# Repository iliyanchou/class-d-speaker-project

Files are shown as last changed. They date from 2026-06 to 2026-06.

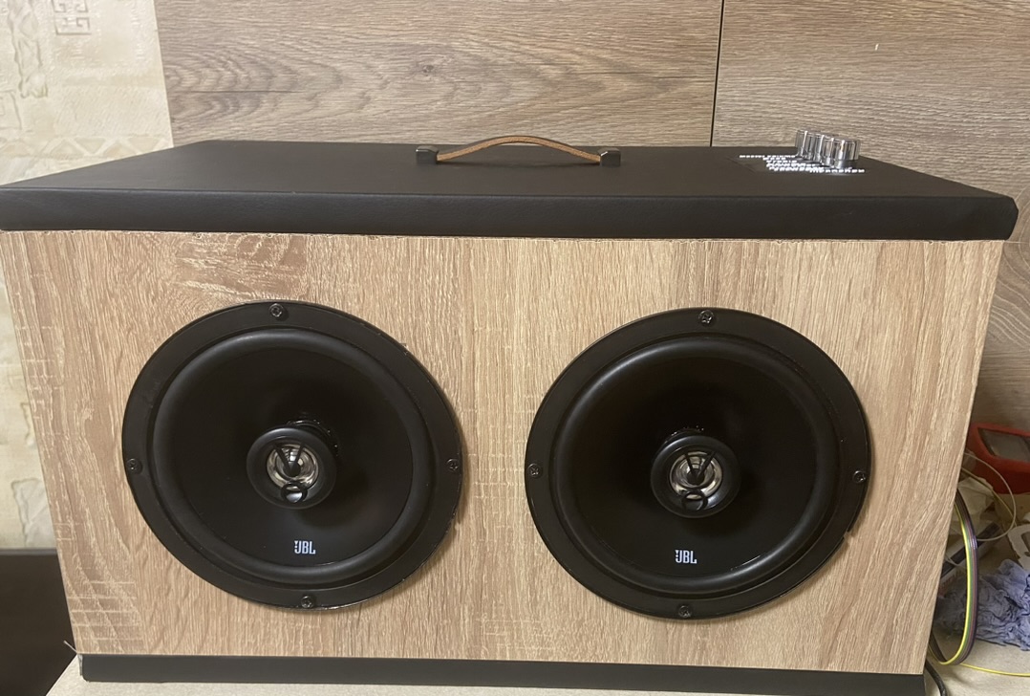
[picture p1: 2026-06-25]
images/FinishedSpeaker.jpeg

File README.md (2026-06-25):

# Class-D Active Speaker Project

This repository presents my diploma engineering project: an active speaker system built around a Class-D amplifier.

## Overview

The project focuses on the design and practical implementation of an active speaker with efficient amplification, wireless audio input, analog input, tone control, and support for external subwoofer connection.

The system combines electronics, acoustics, amplifier theory, digital audio concepts, Bluetooth communication, power supply design, and physical construction.

## Main goals

* Build an active speaker with good sound quality and low distortion
* Use a Class-D amplifier for high efficiency and compact design
* Support Bluetooth audio and AUX input
* Add tone correction and signal control
* Design a portable and practical physical construction
* Document the theory, implementation, and testing process

## Key technologies and topics

* Class-D audio amplification
* PWM-based signal amplification
* Speaker and acoustic enclosure basics
* DSP and digital/analog audio conversion
* Bluetooth audio transmission
* Power supply and battery pack design
* Practical hardware assembly

## Documentation

The full diploma documentation is available in the `docs/` folder.

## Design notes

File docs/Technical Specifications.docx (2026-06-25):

ПРОФЕСИОНАЛНА ГИМНАЗИЯ ПО ВИСОКИ ТЕХНОЛОГИИ „А.С.ПОПОВ“ – гр. София

ПРАКТИЧЕСКАТА РЕАЛИЗАЦИЯ на дипломен проект на тема:

Активна Тонколона

Дипломант: Ръководител на ДП:

Илия Николаев Гранчулов инж. Йорданка Борисова

###### Специалност:

###### Компютърна техника и технологии

###### Клас: 12 ”Г”

София, 2025г.

1. Предназначение и функционалност

Изделието представлява активна аудиосистема, предназначена за домашна или мобилна употреба, с възможност за безжично управление и висококачествено възпроизвеждане на звук.

2. Технически характеристики
- Тип система: Двулентова активна аудиосистема със външен суббуфер
- Брой канали: 2 + 1 – ляв, десен и суббуфер
- Входна комуникация: Bluetooth 5.0, AUX(3.5mm)
- Изходна мощност: 2x20W + 40W (при свързан суббуфер)
- Захранване: Литиево-йонен пакет от 4 клетки с номинално напрежение от 14.8VDC. Зареждане посредством USB тип C.
- Управление: Вграден ключ за включване и изключване, ключ за заглушаване и тонкоректор.
- Честотен обхват: 55Hz ÷ 20kHz
- Импеданс на високоговорителите: 4Ω
- Чувствителност на високоговорителите: 90dB (2.83V)
- Работна дистанция на безжичната комуникация: 10m
- Живот на батерията – 2ч. (80% сила на звука)
- Време за зареждане – 1ч. (15мин ↔ до 45 мин възпроизвеждане)
3. Техническа документация
- Електрическа схема на свързване /стр. 3/

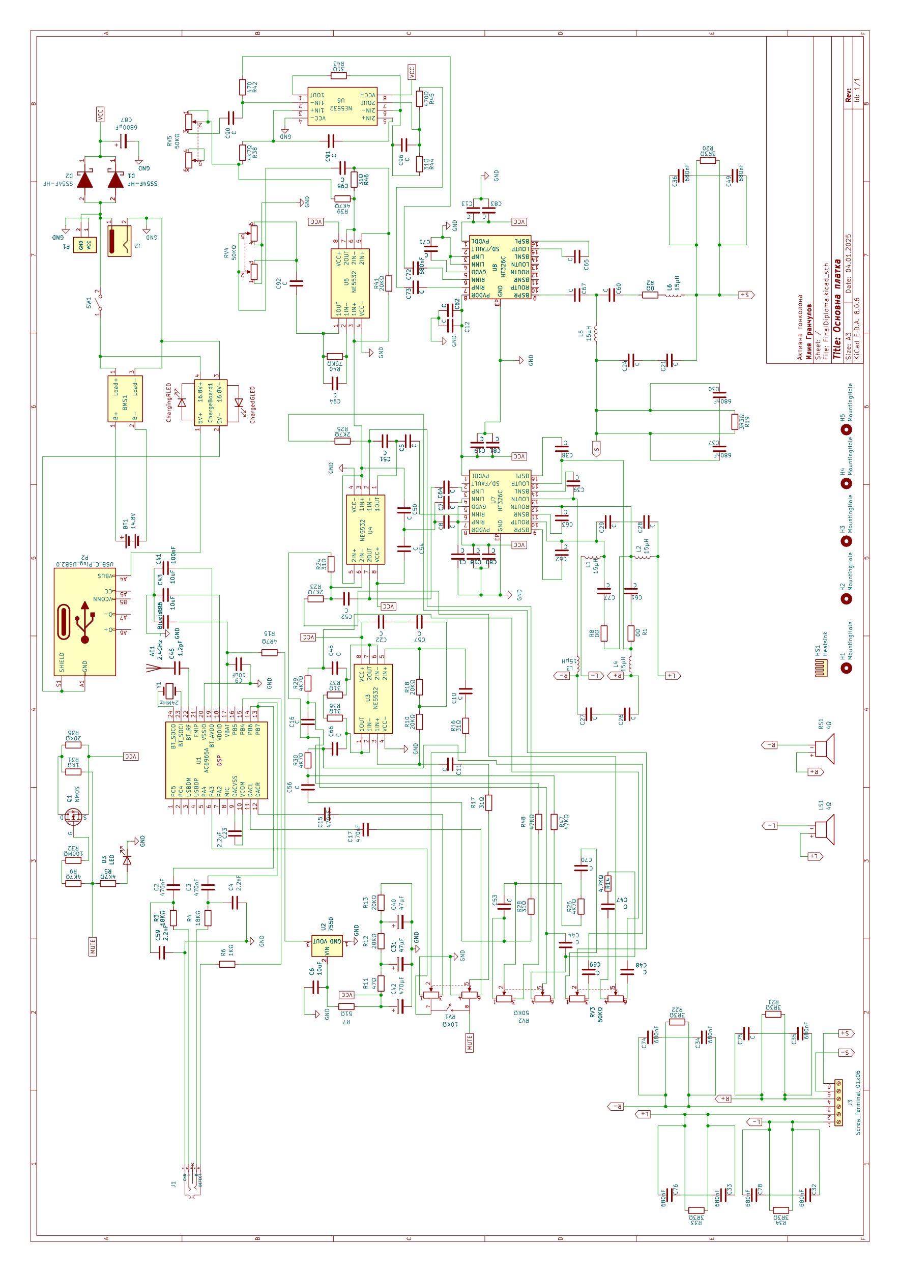
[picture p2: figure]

- Спецификация на използваните елементи

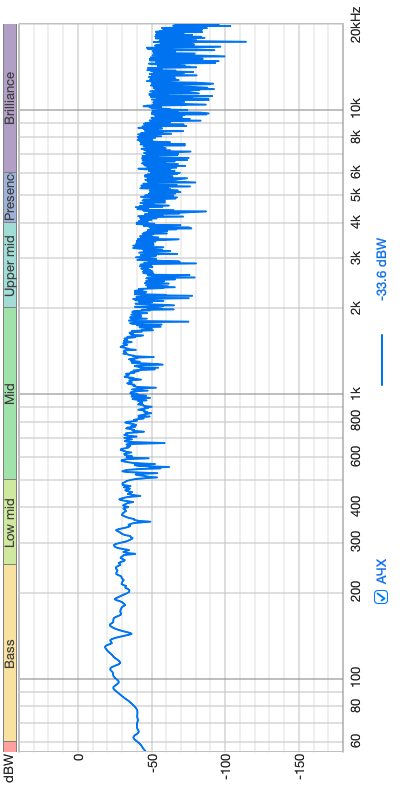
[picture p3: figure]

- Амплитудно-честотна характеристика

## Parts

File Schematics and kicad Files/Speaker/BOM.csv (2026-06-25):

Reference | Value | Datasheet | Footprint | Qty | DNP
4S1 | 14.8V / 3700mAh | ~ |  | 1
AMSRL1-7805JZ1,J2,µC-ESP32 | ~ |  | -- mixed values -- | 3
C1,C3,C6,C13,C33,C62,C63,C64 | 10µF | ~ | -- mixed values -- | 8
C2,C4,C5,C14,C19,C20,C25,C26,C28,C38,C40,C59,C66,C67 | 100nF | ~ | Capacitor_SMD:C_0805_2012Metric_Pad1.18x1.45mm_HandSolder | 14
C7,C8,C15,C16 | 470nF | ~ | Capacitor_SMD:C_0805_2012Metric_Pad1.18x1.45mm_HandSolder | 4
C9,C10 | 2.2nF | ~ | Capacitor_SMD:C_0805_2012Metric_Pad1.18x1.45mm_HandSolder | 2
C11,C12,C29,C30 | 2.2µF | ~ | Capacitor_SMD:C_1206_3216Metric_Pad1.33x1.80mm_HandSolder | 4
C17,C23 | 18nF | ~ | Capacitor_SMD:C_0805_2012Metric_Pad1.18x1.45mm_HandSolder | 2
C18,C24 | 22nF | ~ | Capacitor_SMD:C_0805_2012Metric_Pad1.18x1.45mm_HandSolder | 2
C21,C22 | 5.6nF | ~ | Capacitor_SMD:C_0805_2012Metric_Pad1.18x1.45mm_HandSolder | 2
C27 | 47µF | ~ | Capacitor_THT:CP_Radial_D6.3mm_P2.50mm | 1
C31,C32,C39,C46,C47,C52,C53,C58 | 1nF | ~ | Capacitor_SMD:C_0805_2012Metric_Pad1.18x1.45mm_HandSolder | 8
C34,C35,C36 | 1µF | ~ | Capacitor_SMD:C_0805_2012Metric_Pad1.18x1.45mm_HandSolder | 3
C37,C48,C49,C54,C55 | 10nF | ~ | Capacitor_SMD:C_0805_2012Metric_Pad1.18x1.45mm_HandSolder | 5
C41,C60 | 220µF | ~ | Capacitor_THT:CP_Radial_D10.0mm_P5.00mm | 2
C42,C43,C56,C57 | 220nF | ~ | Capacitor_SMD:C_0805_2012Metric_Pad1.18x1.45mm_HandSolder | 4
C44,C45,C50,C51 | 680nF | ~ | Capacitor_SMD:C_0805_2012Metric_Pad1.18x1.45mm_HandSolder | 4
C61 | 22µF | ~ | Capacitor_SMD:C_0805_2012Metric_Pad1.18x1.45mm_HandSolder | 1
C65 | 4.7µF | ~ | Capacitor_SMD:C_0805_2012Metric_Pad1.18x1.45mm_HandSolder | 1
IC1 | PCM5102APWR | https://componentsearchengine.com/Datasheets/2/PCM5102APWR.pdf | Dip:SOP65P640X120-20N | 1
IC2 | TDA7439DS13TR | https://www.st.com/resource/en/datasheet/tda7439ds.pdf | Dip:SOIC127P1032X265-28N | 1
IC3 | TPA3129D2DAP | http://www.ti.com/lit/gpn/tpa3129d2 | Dip:SOP65P810X120-33N | 1
J4 | Screw_Terminal_01x04 | ~ | TerminalBlock_Phoenix:TerminalBlock_Phoenix_MKDS-1,5-4-5.08_1x04_P5.08mm_Horizontal | 1
L1,L2,L3,L4,L5 | 10µH | ~ | -- mixed values -- | 5
L6 | 12µH | ~ |  | 1
LS1,RS1 | 8Ω | ~ |  | 2
PS1 | R-78E9.0-0.5 | https://www.recom-power.com/pdf/Innoline/R-78Exx-0.5.pdf | R78E1205 | 1
R1,R2,R13,R14 | 470Ω | ~ | Resistor_SMD:R_0805_2012Metric_Pad1.20x1.40mm_HandSolder | 4
R3 | 4.7kΩ | ~ | Resistor_SMD:R_0805_2012Metric_Pad1.20x1.40mm_HandSolder | 1
R4,R5,R17,R18 | 10kΩ | ~ | Resistor_SMD:R_0805_2012Metric_Pad1.20x1.40mm_HandSolder | 4
R6 | 1MΩ | ~ | Resistor_SMD:R_0805_2012Metric_Pad1.20x1.40mm_HandSolder | 1
R7,R8 | 5.1kΩ 1% | ~ | Resistor_SMD:R_0805_2012Metric_Pad1.20x1.40mm_HandSolder | 2
R9,R11 | 2.7kΩ | ~ | Resistor_SMD:R_0805_2012Metric_Pad1.20x1.40mm_HandSolder | 2
R10,R12 | 5.6kΩ | ~ | Resistor_SMD:R_0805_2012Metric_Pad1.20x1.40mm_HandSolder | 2
R15,R16 | 100Ω | ~ | Resistor_SMD:R_0805_2012Metric_Pad1.20x1.40mm_HandSolder | 2
R19 | 33Ω | ~ | Resistor_SMD:R_0805_2012Metric_Pad1.20x1.40mm_HandSolder | 1
R20,R21,R22,R23 | 3.3Ω | ~ | Resistor_SMD:R_0805_2012Metric_Pad1.20x1.40mm_HandSolder | 4
RV1 | 120kΩ | ~ | Potentiometer_THT:Potentiometer_ACP_CA6-H2,5_Horizontal | 1
RV2 | 100kΩ | ~ |  | 1
TP1 | MUTE | ~ | Connector_Pin:Pin_D0.7mm_L6.5mm_W1.8mm_FlatFork | 1

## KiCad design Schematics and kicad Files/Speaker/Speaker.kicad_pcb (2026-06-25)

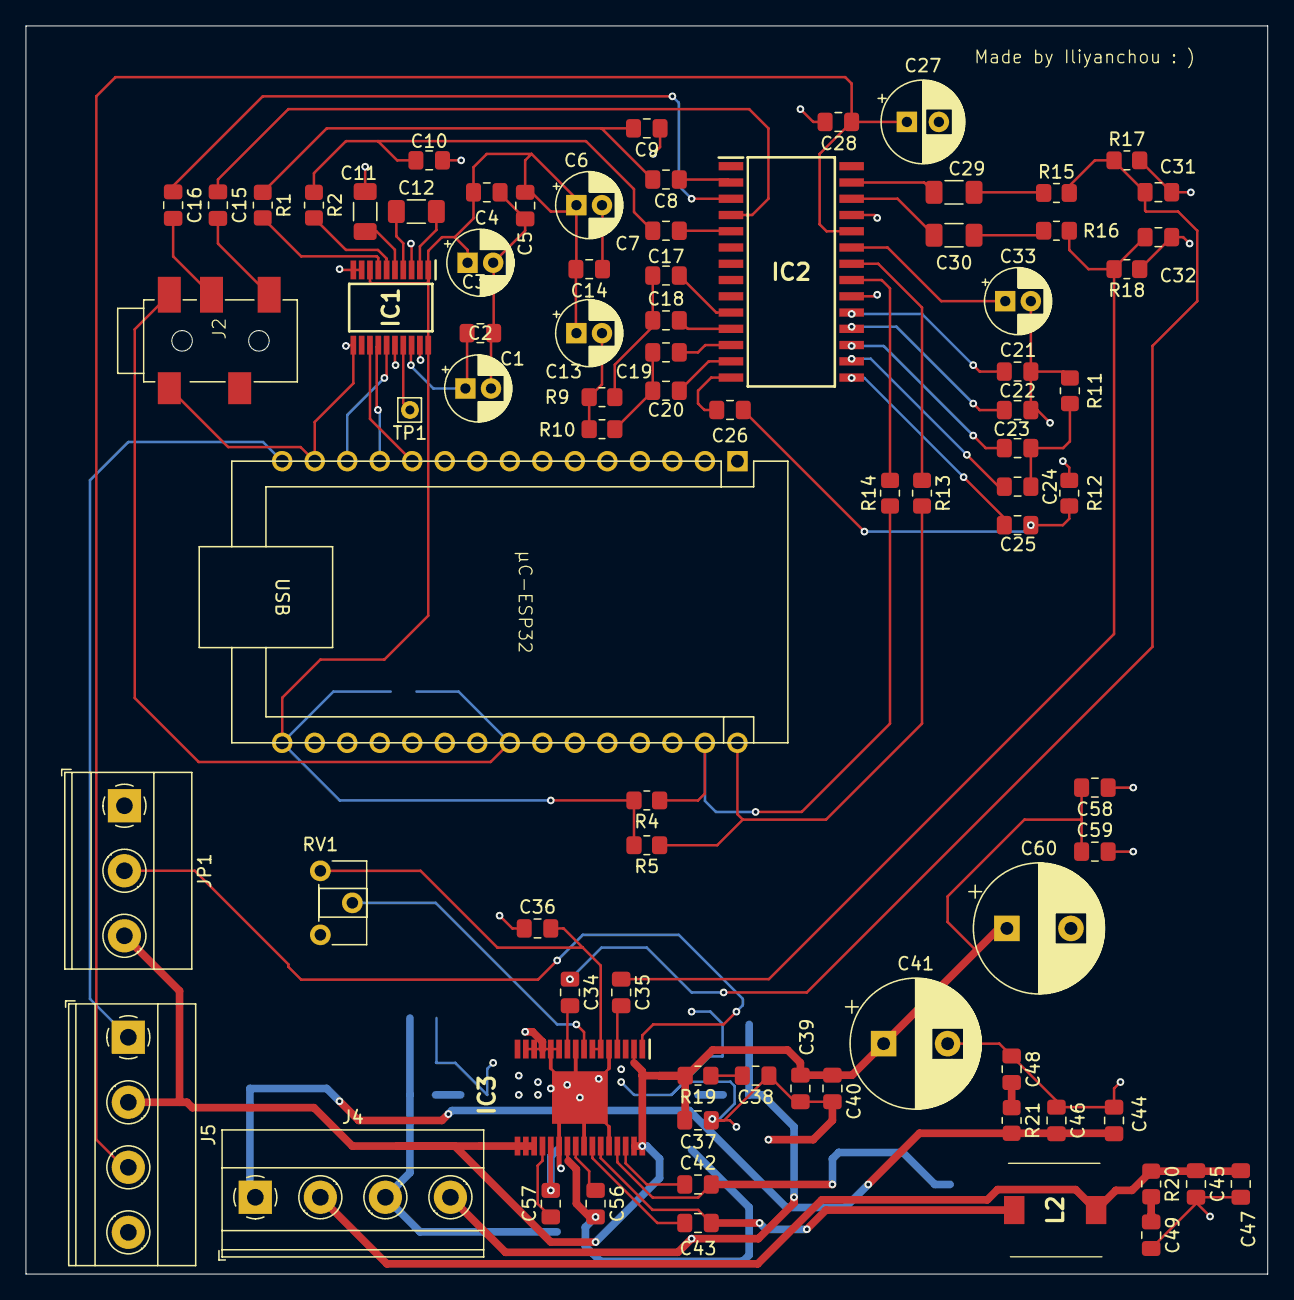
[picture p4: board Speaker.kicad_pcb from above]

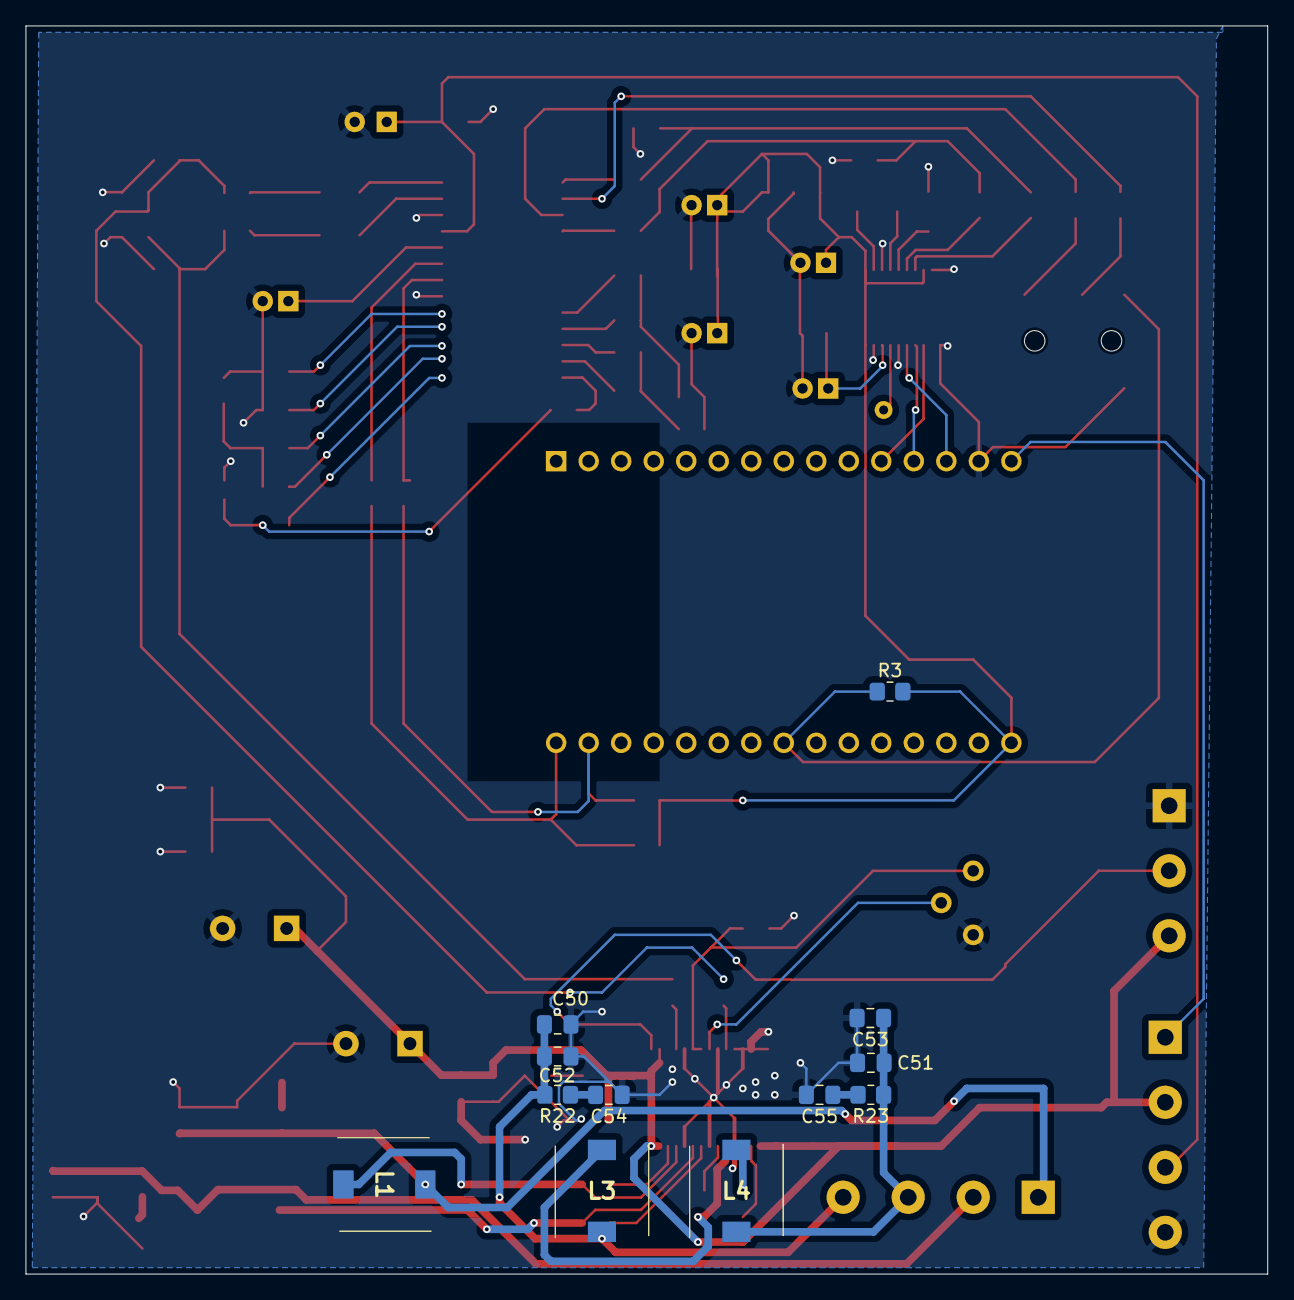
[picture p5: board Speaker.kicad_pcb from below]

Board: 2 copper layers, 97.0 x 97.5 mm, 94 parts (12 on the bottom side), 71 nets.

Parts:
C1, C3, C6, C13, C33: 10µF; CP_Radial_D5.0mm_P2.00mm
C2, C4, C5, C14, C19, C20, C25, C26, C28, C38, C40, C59: 100nF; C_0805_2012Metric_Pad1.18x1.45mm_HandSolder
C7, C8, C15, C16: 470nF; C_0805_2012Metric_Pad1.18x1.45mm_HandSolder
C9, C10: 2.2nF; C_0805_2012Metric_Pad1.18x1.45mm_HandSolder
C11, C12, C29, C30: 2.2µF; C_1206_3216Metric_Pad1.33x1.80mm_HandSolder
C17, C23: 18nF; C_0805_2012Metric_Pad1.18x1.45mm_HandSolder
C18, C24: 22nF; C_0805_2012Metric_Pad1.18x1.45mm_HandSolder
C21, C22: 5.6nF; C_0805_2012Metric_Pad1.18x1.45mm_HandSolder
C27: 47µF; CP_Radial_D6.3mm_P2.50mm
C31, C32, C39, C46, C47, C52, C53, C58: 1nF; C_0805_2012Metric_Pad1.18x1.45mm_HandSolder
C34, C35, C36: 1µF; C_0805_2012Metric_Pad1.18x1.45mm_HandSolder
C37, C48, C49, C54, C55: 10nF; C_0805_2012Metric_Pad1.18x1.45mm_HandSolder
C41, C60: 220µF; CP_Radial_D10.0mm_P5.00mm
C42, C43, C56, C57: 220nF; C_0805_2012Metric_Pad1.18x1.45mm_HandSolder
C44, C45, C50, C51: 680nF; C_0805_2012Metric_Pad1.18x1.45mm_HandSolder
IC1: PCM5102APWR; SOP65P640X120-20N
IC2: TDA7439DS13TR; SOIC127P1032X265-28N
IC3: TPA3129D2DAP; SOP65P810X120-33N
J2: Jack
J4, J5: Screw_Terminal_01x04; TerminalBlock_Phoenix_MKDS-1,5-4-5.08_1x04_P5.08mm_Horizont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
JP1: Jumper_3_Bridged12; TerminalBlock_Phoenix_MKDS-1,5-3-5.08_1x03_P5.08mm_Horizont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
L1, L2, L3, L4: 10µH; CDRH74NP220MCB
R1, R2, R13, R14: 470Ω; R_0805_2012Metric_Pad1.20x1.40mm_HandSolder
R3: 4.7kΩ; R_0805_2012Metric_Pad1.20x1.40mm_HandSolder
R4, R5, R17, R18: 10kΩ; R_0805_2012Metric_Pad1.20x1.40mm_HandSolder
R9, R11: 2.7kΩ; R_0805_2012Metric_Pad1.20x1.40mm_HandSolder
R10, R12: 5.6kΩ; R_0805_2012Metric_Pad1.20x1.40mm_HandSolder
R15, R16: 100Ω; R_0805_2012Metric_Pad1.20x1.40mm_HandSolder
R19: 33Ω; R_0805_2012Metric_Pad1.20x1.40mm_HandSolder
R20, R21, R22, R23: 3.3Ω; R_0805_2012Metric_Pad1.20x1.40mm_HandSolder
RV1: 120kΩ; Potentiometer_ACP_CA6-H2,5_Horizontal
TP1: MUTE; Pin_D0.7mm_L6.5mm_W1.8mm_FlatFork
µC-ESP32: ESP32

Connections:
3V3: C3.1, C4.2, C5.2, C6.1, C13.1, C14.2, IC1.1 (CPVDD), IC1.8 (AVDD), IC1.20 (DVDD), R3.2, R4.2, R5.2, µC-ESP32.1 (3v3)
5VCC: J5.1, µC-ESP32.30 (VIN)
9V VCC: C27.1, C28.1, IC2.24 (VS), J5.3
15VCC: C37.2, C39.2, C40.1, C41.1, C58.2, C59.1, C60.1, IC3.2 (SDZ), IC3.17 (AVCC), IC3.18 (PVCC_1), IC3.19 (PVCC_2), IC3.31 (PVCC_3), IC3.32 (PVCC_4), J5.2, JP1.3 (B), R19.2
GND: C1.2, C2.1, C3.2, C4.1, C5.1, C6.2, C9.1, C10.1, C11.1, C13.2, C14.1, C21.2, C22.2, C27.2, C28.2, C31.1, C32.2, C33.2, C36.1, C37.1, C38.1, C39.1, C40.2, C41.2, C44.1, C45.2, C46.1, C47.2, C48.1, C49.2, C50.1, C51.2, C52.1, C53.2, C54.1, C55.2, C58.1, C59.2, C60.2, IC1.3 (CPGND), IC1.9 (AGND), IC1.10 (DEMP), IC1.11 (FLT), IC1.16 (FMT), IC1.19 (DGND), IC2.20 (DIG-GND), IC2.25 (AGND), IC3.5 (RINN), IC3.9 (GND_1), IC3.11 (LINN), IC3.12 (MUTE), IC3.13 (AM2), IC3.14 (AM1), IC3.15 (AM0), IC3.22 (GND_2), IC3.25 (GND_3), IC3.28 (GND_4), IC3.33 (EP), J2.1 (GND), J5.4, JP1.1 (A), R9.2, R10.1, R11.2, R12.2, R17.2, R18.1, RV1.3, µC-ESP32.29 (GND)
unnamed: C8.2, C9.2, R1.1
unnamed: C7.2, C10.2, R2.1
unnamed: C17.1, C18.1, R9.1
unnamed: C19.1, C20.1, R10.2
unnamed: C23.2, C24.2, R11.1
unnamed: C25.2, C26.1, R12.1
unnamed: C29.2, R15.1
unnamed: C30.2, R16.1
unnamed: C31.2, C34.1, R15.2, R17.1
unnamed: C32.1, C35.1, R16.2, R18.2
unnamed: C38.2, R19.1
unnamed: C48.2, R21.1
unnamed: C49.1, R20.2
unnamed: C54.2, R22.1
unnamed: C55.1, R23.2
unnamed: IC1.13 (BCK), µC-ESP32.26 (D14)
unnamed: C12.1, IC1.4 (CAPM)
unnamed: C12.2, IC1.2 (CAPP)
unnamed: IC1.14 (DIN), µC-ESP32.27 (D12)
unnamed: C1.1, C2.2, IC1.18 (LDOO)
unnamed: IC1.15 (LRCK), µC-ESP32.28 (D13)
unnamed: IC1.6 (OUTL), R2.2
unnamed: IC1.7 (OUTR), R1.2
unnamed: C11.2, IC1.5 (VNEG)
unnamed: IC1.17 (XSMT), TP1.1
unnamed: C26.2, IC2.14 (BIN(L))
unnamed: C19.2, IC2.12 (BIN(R))
unnamed: C25.1, IC2.15 (BOUT(L))
unnamed: C20.2, IC2.13 (BOUT(R))
unnamed: C33.1, IC2.23 (CREF)
unnamed: C29.1, IC2.27 (LOUT)
unnamed: C15.1, IC2.4 (L_IN1)
unnamed: C7.1, IC2.5 (L_IN2)
unnamed: C23.1, IC2.17 (MIN(L))
unnamed: C17.2, IC2.10 (MIN(R))
unnamed: C24.1, IC2.16 (MOUT(L))
unnamed: C18.2, IC2.11 (MOUT(R))
unnamed: C30.1, IC2.26 (ROUT)
unnamed: C16.1, IC2.3 (R_IN1)
unnamed: C8.1, IC2.2 (R_IN2)
unnamed: IC2.21 (SCL), R14.2
unnamed: IC2.22 (SDA), R13.1
unnamed: C22.1, IC2.18 (TREBLE(L))
unnamed: C21.1, IC2.19 (TREBLE(R))
unnamed: C57.1, IC3.20 (BSNL)
unnamed: C43.1, IC3.26 (BSNR)
unnamed: C56.1, IC3.24 (BSPL)
unnamed: C42.1, IC3.30 (BSPR)
unnamed: IC3.8 (GAIN/SLV), RV1.2
unnamed: C36.2, IC3.6 (PLIMIT), IC3.7 (GVDD), RV1.1
unnamed: C34.2, IC3.10 (LINP)
unnamed: IC3.1 (MODSEL), JP1.2 (C)
unnamed: C57.2, IC3.21 (OUTNL), L4.2
unnamed: C43.2, IC3.27 (OUTNR), L2.2
unnamed: C56.2, IC3.23 (OUTPL), L3.1
unnamed: C42.2, IC3.29 (OUTPR), L1.1
unnamed: C35.2, IC3.4 (RINP)
unnamed: J2.5 (DETECT), R3.1, µC-ESP32.8 (D5)
unnamed: C15.2, J2.4 (L)
unnamed: C16.2, J2.3 (R)
unnamed: C44.2, C46.2, J4.1, L1.2, R21.2
unnamed: C45.1, C47.1, J4.2, L2.1, R20.1
unnamed: C51.1, C53.1, J4.3, L4.1, R23.1
unnamed: C50.2, C52.2, J4.4, L3.2, R22.2
unnamed: R4.1, R14.1, µC-ESP32.14 (D22)
unnamed: R5.1, R13.2, µC-ESP32.15 (D23)
